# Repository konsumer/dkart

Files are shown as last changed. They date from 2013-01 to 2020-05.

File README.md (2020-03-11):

# dkart

An open-hardware and software Gameboy flash-cart and hardware peripheral framework that uses off-the-shelf hardware. The goal is to be ultra-cheap and simple.

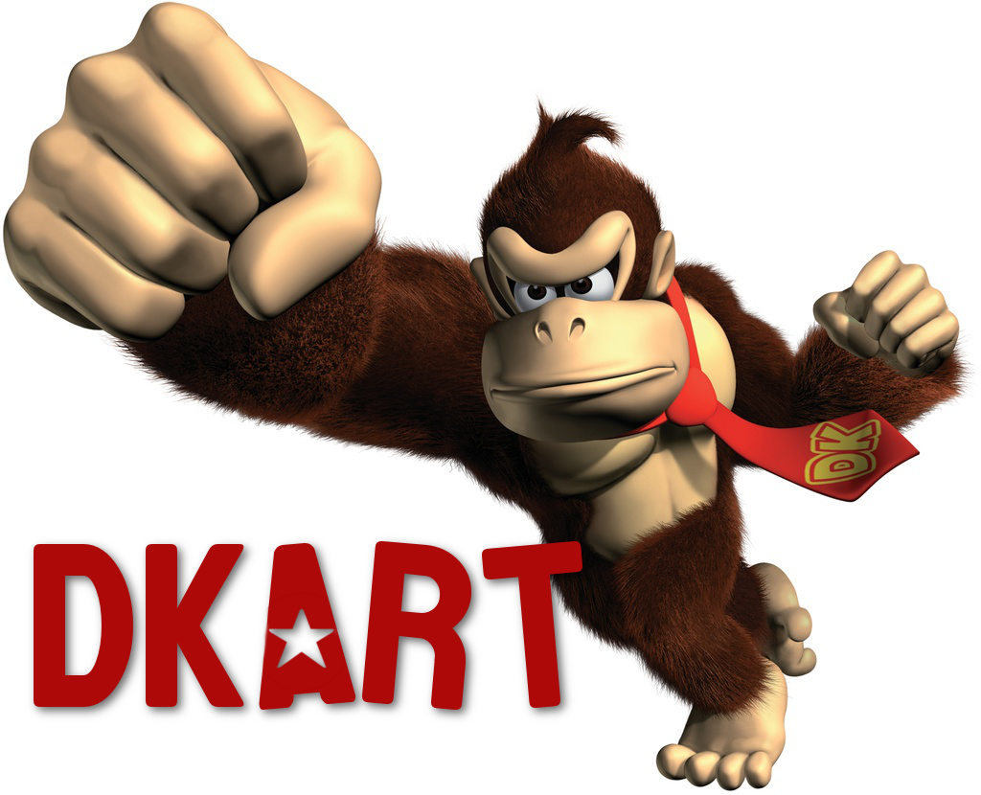
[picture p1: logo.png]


## quickstart

If you just want to get started, go to [releases](https://github.com/konsumer/dkart/releases) and grab `dkart.gb`, and put it on a FAT32-formatted SDCard. Solder together the hardware, plug it in, and startup your gameboy.

## Hardware

It's meant to be very cheap & easy to put together. I made a PCB, and you can just solder in a [cheap ESP32 board](https://www.banggood.com/Geekcreit-ESP32-WiFibluetooth-Development-Board-Ultra-Low-Power-Consumption-Dual-Cores-Unsoldered-p-1214159.html) and the [SDCard shield](https://www.banggood.com/SD-Card-Module-Slot-Socket-Reader-Mp3-player-p-74105.html), and it should work.

Originally, I designed this as a custom circuit with really low-resource chips, but realized it was much easier and cheaper to just use more modern ready-made stuff.

Eventually I'd like to add an i2c bus that can be triggered/read from gameboy, so users can easily mess with hardware peripherals.

I am still working on the PCB & schematic. You can open hardware/Dkart.json at [easyeda](https://easyeda.com/).

### under consideration

Here are some other ideas I am looking at:

* [STM32F401](https://www.banggood.com/STM32F401-Development-Board-STM32F401CCU6-STM32F4-Learning-Board-p-1568897.html)
* [This board](https://www.banggood.com/LILYGO-TTGO-T2-ESP32-0_95-OLED-SD-Card-WiFi-bluetooth-Module-Development-Board-p-1270477.html) has a SDCard and OLED screen (and wifi/bluetooth)
* [cheap atmega2560 board](https://robotdyn.com/mega-2560-pro-mini-atmega2560-16au.html), works with arduino & has more IO/RAM/CPU, but still not big enough to hold every ROM
* [fast flash mem](https://www.sparkfun.com/products/15809) - I could load the rom & ram into flash temporarily on a lower-end microcontroller, then feed the data to the GB.
* [something like this](https://www.banggood.com/GY-Openlog-Cleanflight-Naze32-F3-Blackbox-Flash-Recorder-Module-p-1309673.html) has a lot of storage (32GB) but might not be fast enough
* [ready-made cart PCB](https://store.kitsch-bent.com/product/kk_gb_brkout) - with a little simple soldering and a big flash chip, I could probly get it all to fit inside a cartridge
* [something like this](http://ww1.microchip.com/downloads/en/DeviceDoc/20005023B.pdf) could be hooked up directly to GB pins, with maybe a little simple mode-management from a micro
* [sdfat](https://github.com/greiman/SdFat-beta) can do 3965.11 KB/Sec transfer in dedicated SPI with a slow cad, which should be fast enough
* [better SDCards](https://www.cameramemoryspeed.com/sd-memory-card-faq/fastest-memory-card/) can go much faster, so make sure to check SD speed (SDFst has a `bench` sketch)
* 3d print longer cart to hold more electronics if needed. [here](https://www.thingiverse.com/thing:2882206) are some nice variations. [Here](https://www.thingiverse.com/thing:3101147) is a nice modular design (opnscad - chnage logo, etc)
* I have a [ATxmega128A1 breakout](https://www.sparkfun.com/products/retired/9546) laying around, but it's discontinued at sparkfun. It has 78 IO and 32 MIPS! It only has 128kB of flash memory & 8 kB SRAM, but could be used easily with other things, possibly SD alone is fast enough.
* look at [this ESP32 cart](https://hackaday.io/project/20769-wifi-game-boy-cartridge). They have a lot of the same ideas.

## Firmware

The firmware runs on the device to emulate ROM/RAM reading/writing data to a microSD card formatted FAT16/FAT32/ExFat. The firmware is meant to be compiled in Arduino IDE. If you open serial-monitor when it's running, you'll see some debugging output. On Arch Linux, I had to use `arduino-PR-beta1.9-BUILD-117` for serial-monitor to work, due to some java error.

Files should all be in the root of the SDCard. The fRAM-size is 128K so you may hit limits if you have a ton of ROM files on the SD (limit should be around 8,737.) The file-list uses ROM-header-title, so if you have a bunch of the same ROM file-named differently, it will work, but in the ROM-list they will all have the same name. You can use this trick to have different copies of the same ROM with separate RAM files (like 1-per-song for nanoloop, for example.)

## Software

A menu runs on the Gameboy to choose the current ROM/RAM. When a ROM is chosen, the gameboy reboots using that ROM/RAM.

To compile, run

```sh
make
```

in the software directory. 

You can read more about it in [software](./software/README.md).

## TODO

* Actually Implement MBC1
* Get SD-loading working (on boot load into RAM from SD while playing logo)
* Get menu working (get list of ROMs from firmware, on menu selection, set mem, load on reboot & clear mem)
* Implement MBC5
* Replace Nintendo logo with mine
* add extra IO-functionality, reading/writing to a specific memory location to turn on "I/O mode" and be able to interface with other peripherals
* Add support for sub-directories
* Create a modern cross-platform GBDK-focused full dev-env (use wine & docker to run stuff like GBTD.) Alternately, write some web-based tools around GBDK.js to allow sprite/map/sound editing.

## License

* Hardware is licensed 
* Firmware & Software is licensed GPLv3

## Thanks

* Lots of hardware/firmware ideas from [here](https://dhole.github.io/post/gameboy_cartridge_emu_1/)
* Ideas for menu ROM programming from [gbdk_playground](https://github.com/mrombout/gbdk_playground), [gbdk-salvage](https://github.com/gbdk-salvage/grooves-game-boy-programming), & [GBSoundDemo](https://github.com/Zal0/GBSoundDemo)

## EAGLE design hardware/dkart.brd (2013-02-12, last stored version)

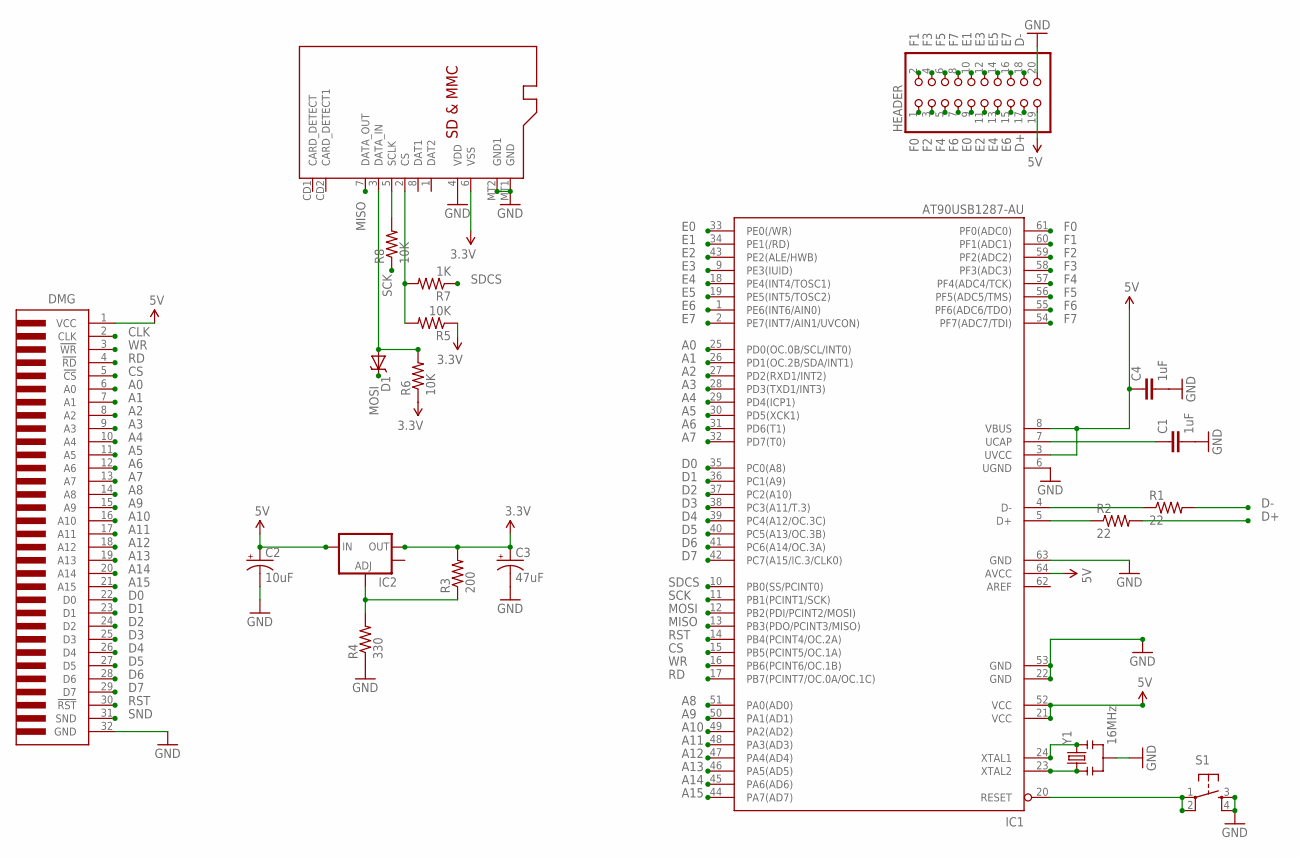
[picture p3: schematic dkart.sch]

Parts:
C1, C4: 1uF; 0805
C2: 10uF; EIA3528-KIT
C3: 47uF; EIA3528-KIT
D1: B340A; SMA-DIODE
DMG: GBCART-FULL; GBCART
HEADER: PINHD-2X10/90; 2X10/90
IC1: AT90USB1287-AU; TQFP64
IC2: V_REG_LM1117SOT223; SOT223
R1, R2: 22; 0805
R3: 200; 0805
R4: 330; 0805
R5, R6, R8: 10K; 0805
R7: 1K; 0805
S1: TAC_SWITCHSMD; TACTILE_SWITCH_SMD
SD: MICROSD
Y1: 16MHz; RESONATOR-SMD

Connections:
3.3V: C3.A (+), IC2.2 (OUT), R3.2, R5.1, R6.1, SD.6 (VSS)
5V: C2.A (+), C4.1, DMG.1 (VCC), HEADER.19, IC1.3 (UVCC), IC1.8 (VBUS), IC1.21 (VCC), IC1.52 (VCC), IC1.64 (AVCC), IC2.3 (IN)
A0: DMG.6 (A0), IC1.25 (PD0(OC.0B/SCL/INT0))
A1: DMG.7 (A1), IC1.26 (PD1(OC.2B/SDA/INT1))
A2: DMG.8 (A2), IC1.27 (PD2(RXD1/INT2))
A3: DMG.9 (A3), IC1.28 (PD3(TXD1/INT3))
A4: DMG.10 (A4), IC1.29 (PD4(ICP1))
A5: DMG.11 (A5), IC1.30 (PD5(XCK1))
A6: DMG.12 (A6), IC1.31 (PD6(T1))
A7: DMG.13 (A7), IC1.32 (PD7(T0))
A8: DMG.14 (A8), IC1.51 (PA0(AD0))
A9: DMG.15 (A9), IC1.50 (PA1(AD1))
A10: DMG.16 (A10), IC1.49 (PA2(AD2))
A11: DMG.17 (A11), IC1.48 (PA3(AD3))
A12: DMG.18 (A12), IC1.47 (PA4(AD4))
A13: DMG.19 (A13), IC1.46 (PA5(AD5))
A14: DMG.20 (A14), IC1.45 (PA6(AD6))
A15: DMG.21 (A15), IC1.44 (PA7(AD7))
CLK: DMG.2 (CLK)
CS: DMG.5 (!CS), IC1.15 (PB5(PCINT5/OC.1A))
D0: DMG.22 (D0), IC1.35 (PC0(A8))
D1: DMG.23 (D1), IC1.36 (PC1(A9))
D2: DMG.24 (D2), IC1.37 (PC2(A10))
D3: DMG.25 (D3), IC1.38 (PC3(A11/T.3))
D4: DMG.26 (D4), IC1.39 (PC4(A12/OC.3C))
D5: DMG.27 (D5), IC1.40 (PC5(A13/OC.3B))
D6: DMG.28 (D6), IC1.41 (PC6(A14/OC.3A))
D7: DMG.29 (D7), IC1.42 (PC7(A15/IC.3/CLK0))
D+: HEADER.17, R2.2
D-: HEADER.18, R1.2
E0: HEADER.9, IC1.33 (PE0(/WR))
E1: HEADER.10, IC1.34 (PE1(/RD))
E2: HEADER.11, IC1.43 (PE2(ALE/HWB))
E3: HEADER.12, IC1.9 (PE3(IUID))
E4: HEADER.13, IC1.18 (PE4(INT4/TOSC1))
E5: HEADER.14, IC1.19 (PE5(INT5/TOSC2))
E6: HEADER.15, IC1.1 (PE6(INT6/AIN0))
E7: HEADER.16, IC1.2 (PE7(INT7/AIN1/UVCON))
F0: HEADER.1, IC1.61 (PF0(ADC0))
F1: HEADER.2, IC1.60 (PF1(ADC1))
F2: HEADER.3, IC1.59 (PF2(ADC2))
F3: HEADER.4, IC1.58 (PF3(ADC3))
F4: HEADER.5, IC1.57 (PF4(ADC4/TCK))
F5: HEADER.6, IC1.56 (PF5(ADC5/TMS))
F6: HEADER.7, IC1.55 (PF6(ADC6/TDO))
F7: HEADER.8, IC1.54 (PF7(ADC7/TDI))
GND: C1.2, C2.C (-), C3.C (-), C4.2, DMG.32 (GND), HEADER.20, IC1.6 (UGND), IC1.22 (GND), IC1.53 (GND), IC1.63 (GND), R4.1, S1.3, S1.4, SD.4 (VDD), SD.MT1 (GND), SD.MT2 (GND1), Y1.2
MISO: IC1.13 (PB3(PDO/PCINT3/MISO)), SD.7 (DATA_OUT)
MOSI: D1.C, IC1.12 (PB2(PDI/PCINT2/MOSI))
unnamed: IC1.24 (XTAL1), Y1.3
unnamed: IC1.23 (XTAL2), Y1.1
unnamed: IC1.20 (RESET), S1.1, S1.2
unnamed: IC1.5 (D+), R2.1
unnamed: IC1.4 (D-), R1.1
unnamed: C1.1, IC1.7 (UCAP)
unnamed: IC2.1 (ADJ), R3.1, R4.2
unnamed: R8.2, SD.5 (SCLK)
unnamed: D1.A, R6.2, SD.3 (DATA_IN)
unnamed: R5.2, R7.2, SD.2 (CS)
RD: DMG.4 (!RD), IC1.17 (PB7(PCINT7/OC.0A/OC.1C))
RST: DMG.30 (!RST), IC1.14 (PB4(PCINT4/OC.2A))
SCK: IC1.11 (PB1(PCINT1/SCK)), R8.1
SDCS: IC1.10 (PB0(SS/PCINT0)), R7.1
SND: DMG.31 (SND)
WR: DMG.3 (!WR), IC1.16 (PB6(PCINT6/OC.1B))

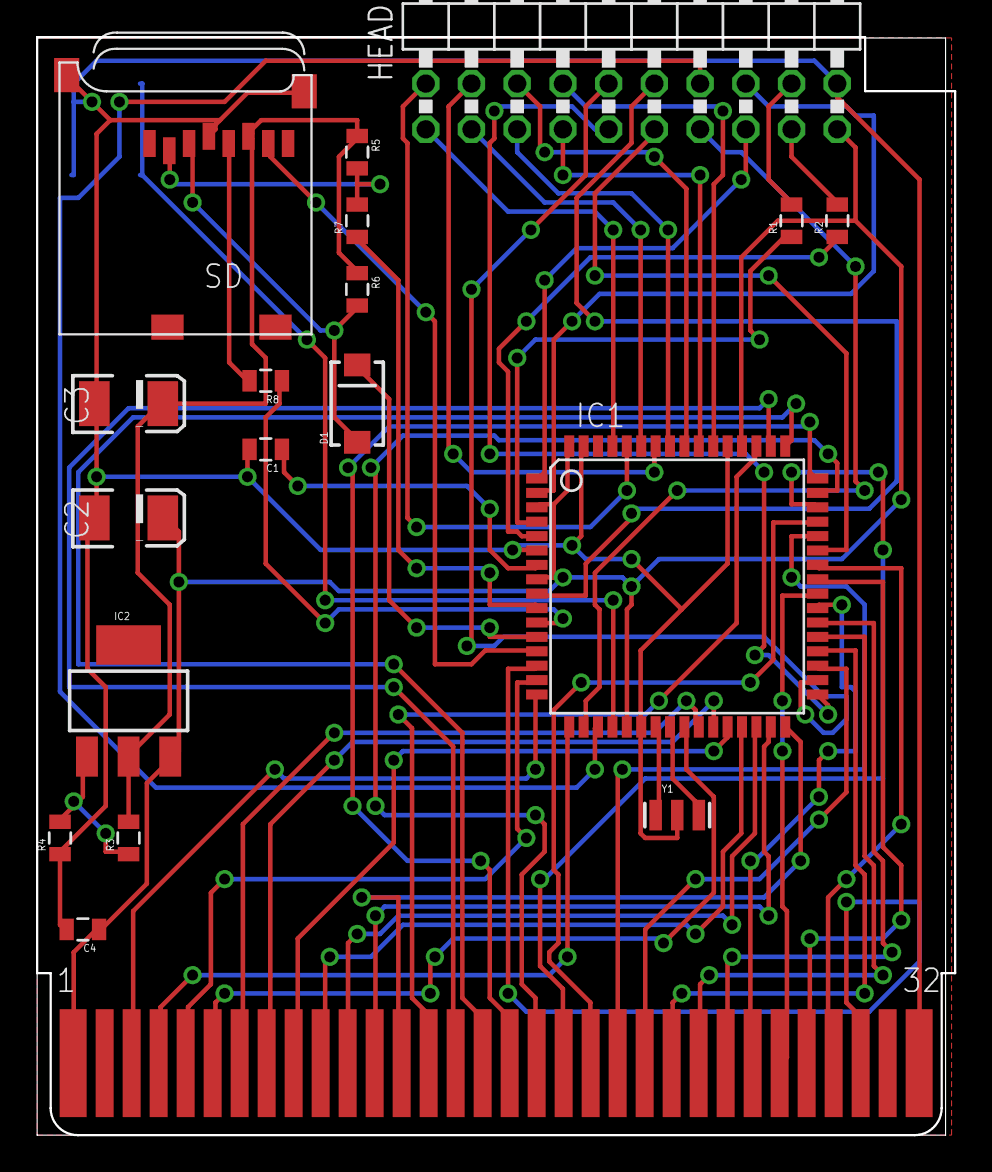
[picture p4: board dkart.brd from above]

Board: 2 copper layers, 51.0 x 61.0 mm, 20 parts (1 on the bottom side), 63 nets.

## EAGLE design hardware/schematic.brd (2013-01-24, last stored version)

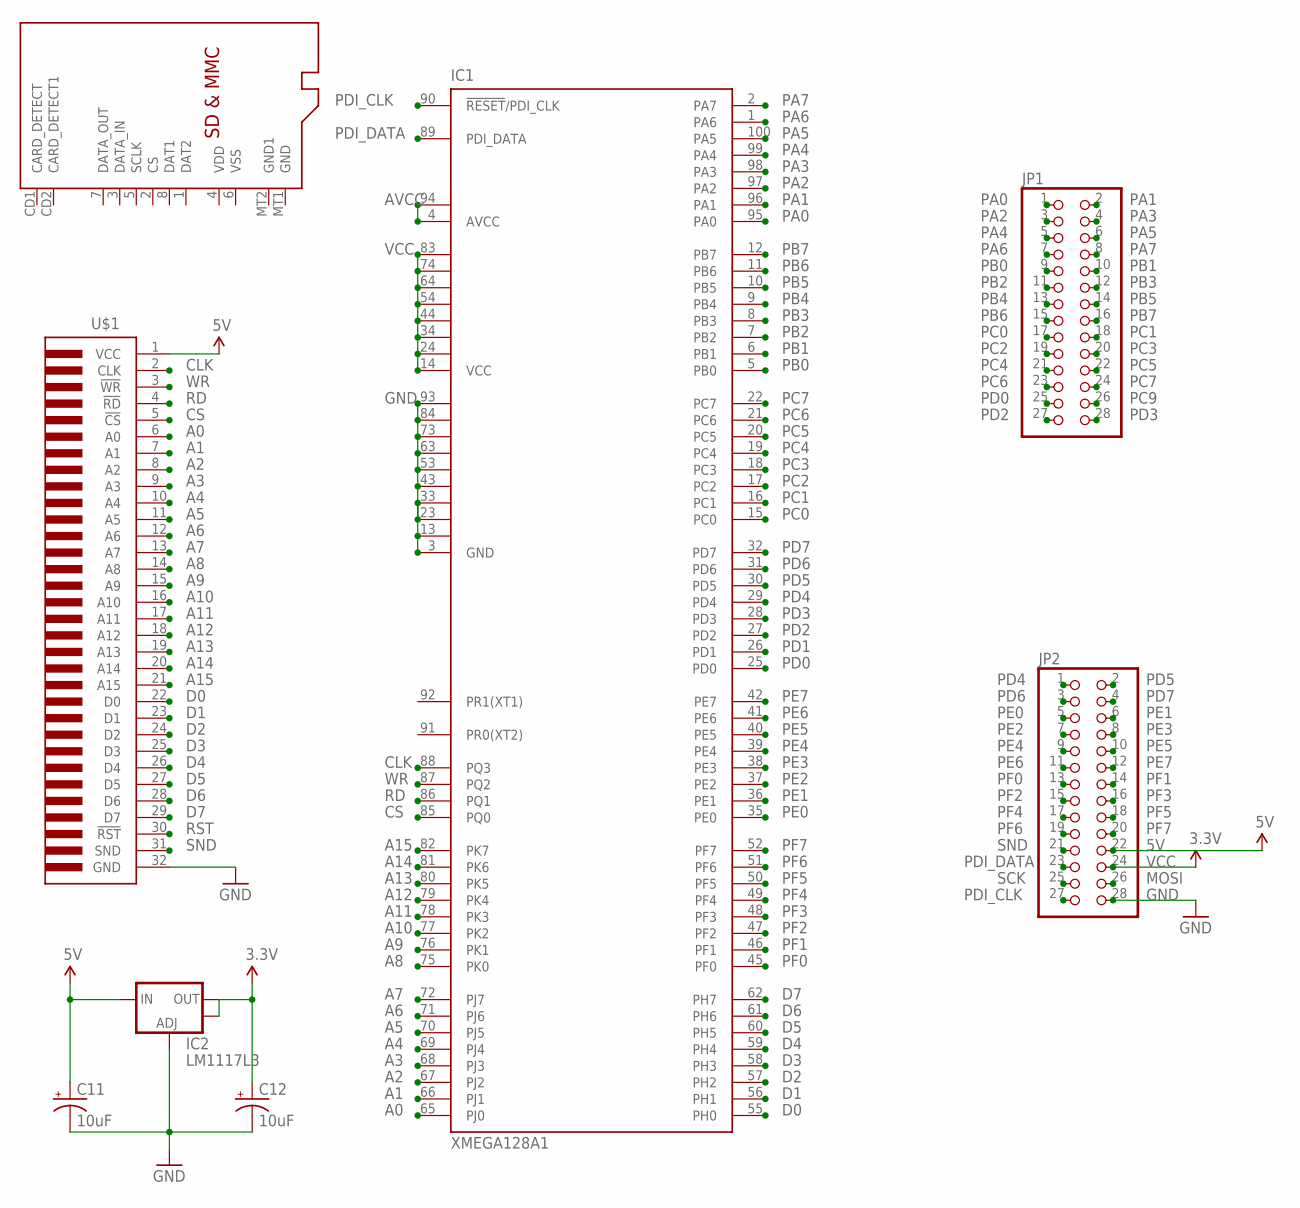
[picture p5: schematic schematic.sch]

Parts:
C11, C12: 10uF; EIA3216
IC1: XMEGA128A1; TQFP100
IC2: LM1117L3; SOT223
JP1, JP2: PINHD-2X14-CB; 2X14-CLEANBIG
U$1: GBCART-FULL; GBCART
U$5: MICROSD

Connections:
5V: C11.A (+), IC2.3 (IN), JP2.22, U$1.1 (VCC)
A0: IC1.65 (PJ0), U$1.6 (A0)
A1: IC1.66 (PJ1), U$1.7 (A1)
A2: IC1.67 (PJ2), U$1.8 (A2)
A3: IC1.68 (PJ3), U$1.9 (A3)
A4: IC1.69 (PJ4), U$1.10 (A4)
A5: IC1.70 (PJ5), U$1.11 (A5)
A6: IC1.71 (PJ6), U$1.12 (A6)
A7: IC1.72 (PJ7), U$1.13 (A7)
A8: IC1.75 (PK0), U$1.14 (A8)
A9: IC1.76 (PK1), U$1.15 (A9)
A10: IC1.77 (PK2), U$1.16 (A10)
A11: IC1.78 (PK3), U$1.17 (A11)
A12: IC1.79 (PK4), U$1.18 (A12)
A13: IC1.80 (PK5), U$1.19 (A13)
A14: IC1.81 (PK6), U$1.20 (A14)
A15: IC1.82 (PK7), U$1.21 (A15)
AVCC: IC1.4 (AVCC), IC1.94 (AVCC1)
CLK: IC1.88 (PQ3), U$1.2 (CLK)
CS: IC1.85 (PQ0), U$1.5 (!CS)
D0: IC1.55 (PH0), U$1.22 (D0)
D1: IC1.56 (PH1), U$1.23 (D1)
D2: IC1.57 (PH2), U$1.24 (D2)
D3: IC1.58 (PH3), U$1.25 (D3)
D4: IC1.59 (PH4), U$1.26 (D4)
D5: IC1.60 (PH5), U$1.27 (D5)
D6: IC1.61 (PH6), U$1.28 (D6)
D7: IC1.62 (PH7), U$1.29 (D7)
GND: C11.C (-), C12.C (-), IC1.3 (GND), IC1.13 (GND1), IC1.23 (GND2), IC1.33 (GND3), IC1.43 (GND4), IC1.53 (GND5), IC1.63 (GND6), IC1.73 (GND7), IC1.84 (GND8), IC1.93 (GND9), IC2.1 (ADJ), JP2.28, U$1.32 (GND)
MOSI: JP2.26
PA0: IC1.95 (PA0), JP1.1
PA1: IC1.96 (PA1), JP1.2
PA2: IC1.97 (PA2), JP1.3
PA3: IC1.98 (PA3), JP1.4
PA4: IC1.99 (PA4), JP1.5
PA5: IC1.100 (PA5), JP1.6
PA6: IC1.1 (PA6), JP1.7
PA7: IC1.2 (PA7), JP1.8
PB0: IC1.5 (PB0), JP1.9
PB1: IC1.6 (PB1), JP1.10
PB2: IC1.7 (PB2), JP1.11
PB3: IC1.8 (PB3), JP1.12
PB4: IC1.9 (PB4), JP1.13
PB5: IC1.10 (PB5), JP1.14
PB6: IC1.11 (PB6), JP1.15
PB7: IC1.12 (PB7), JP1.16
PC0: IC1.15 (PC0), JP1.17
PC1: IC1.16 (PC1), JP1.18
PC2: IC1.17 (PC2), JP1.19
PC3: IC1.18 (PC3), JP1.20
PC4: IC1.19 (PC4), JP1.21
PC5: IC1.20 (PC5), JP1.22
PC6: IC1.21 (PC6), JP1.23
PC7: IC1.22 (PC7), JP1.24
PC9: JP1.26
PD0: IC1.25 (PD0), JP1.25
PD1: IC1.26 (PD1)
PD2: IC1.27 (PD2), JP1.27
PD3: IC1.28 (PD3), JP1.28
PD4: IC1.29 (PD4), JP2.1
PD5: IC1.30 (PD5), JP2.2
PD6: IC1.31 (PD6), JP2.3
PD7: IC1.32 (PD7), JP2.4
PDI_CLK: IC1.90 (!RESET!/PDI_CLK), JP2.27
PDI_DATA: IC1.89 (PDI_DATA), JP2.23
PE0: IC1.35 (PE0), JP2.5
PE1: IC1.36 (PE1), JP2.6
PE2: IC1.37 (PE2), JP2.7
PE3: IC1.38 (PE3), JP2.8
PE4: IC1.39 (PE4), JP2.9
PE5: IC1.40 (PE5), JP2.10
PE6: IC1.41 (PE6), JP2.11
PE7: IC1.42 (PE7), JP2.12
PF0: IC1.45 (PF0), JP2.13
PF1: IC1.46 (PF1), JP2.14
PF2: IC1.47 (PF2), JP2.15
PF3: IC1.48 (PF3), JP2.16
PF4: IC1.49 (PF4), JP2.17
PF5: IC1.50 (PF5), JP2.18
PF6: IC1.51 (PF6), JP2.19
PF7: IC1.52 (PF7), JP2.20
RD: IC1.86 (PQ1), U$1.4 (!RD)
RST: U$1.30 (!RST)
SCK: JP2.25
SND: JP2.21, U$1.31 (SND)
VCC: C12.A (+), IC1.14 (VCC), IC1.24 (VCC1), IC1.34 (VCC2), IC1.44 (VCC3), IC1.54 (VCC4), IC1.64 (VCC5), IC1.74 (VCC6), IC1.83 (VCC7), IC2.2 (OUT), IC2.4 (OUT), JP2.24
WR: IC1.87 (PQ2), U$1.3 (!WR)

Board: 2 copper layers, 8 parts (0 on the bottom side), 82 nets, no tracks yet.

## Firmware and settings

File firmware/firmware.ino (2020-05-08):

/*
HARDWARE:

ESP32: https://www.banggood.com/Geekcreit-ESP32-WiFibluetooth-Development-Board-Ultra-Low-Power-Consumption-Dual-Cores-Unsoldered-p-1214159.html
SDCard hooked to P5 (SS), P18 (SCK), P19 (MISO), P23 (MOSI)

Currently this just builds a dkart.sav from the current file-list
*/

// use https://github.com/greiman/SdFat-beta
#include "SdFat.h"

// this defines the hardware

// SD on HSPI - http://www.ayarafun.com/wp-content/uploads/2016/11/esp32-pinout.png
// MISO - 12
// MOSI - 13
// SCK - 14
// SS - 15

// https://dhole.github.io/media/gameboy_stm32f4/gb_cartridge_pins.jpg

// it's maxed-out, so no i2c or serial or wifi
// probly should use a shift-in (like 74F676) to handle GB address
// with i2s sort of like this:
// https://github.com/Crypter/CryptoIO
// https://github.com/lhartmann/esp8266_reprap
// https://esp32.com/viewtopic.php?f=17&t=3188
// i2s allows very fast low-cpu serial

#define GB_A0  GPIO36
#define GB_A1  GPIO39
#define GB_A2  GPIO34
#define GB_A3  GPIO35
#define GB_A4  GPIO32
#define GB_A5  GPIO33
#define GB_A6  GPIO25
#define GB_A7  GPIO26
#define GB_A8  GPIO27
#define GB_A9  GPIO09
#define GB_A10 GPIO10
#define GB_A11 GPIO11
#define GB_A12 GPIO23
#define GB_A13 GPIO22
#define GB_A14 GPIO01
#define GB_A15 GPIO03

#define GB_D0  GPIO21
#define GB_D1  GPIO19
#define GB_D2  GPIO18
#define GB_D3  GPIO05
#define GB_D4  GPIO17
#define GB_D5  GPIO16
#define GB_D6  GPIO04
#define GB_D7  GPIO00

#define GB_WR  GPIO02
#define GB_RD  GPIO08
#define GB_CLK GPIO07
#define GB_CS  GPIO06

// #define GB_RST
#define GB_AUD ADC12 // GPIO02

// this is maybe a bit specifc to my hardware, see SdFat examples to tune to yours, if needed
#define SD_CONFIG SdSpiConfig(SS, DEDICATED_SPI, SD_SCK_MHZ(16))

#define error(s) { errState = true; sd.errorHalt(&Serial, F(s)); }
#define interval 500

// This figures out correct filesystem (EX/FAT16/32)
SdFs sd;
FsFile file;
FsFile root;
FsFile sav;

char romName[15];

unsigned long romCount = 0;
char currentRom[255] = "dkart.gb";
char currentSav[255] = "dkart.sav";

bool errState = false;

// async LED blinker to show error-state
int ledState = LOW;
unsigned long previousMillis = 0;
unsigned long currentMillis = 0;
void ledBlink () {
  currentMillis = millis();
  if (currentMillis - previousMillis >= interval) {
    previousMillis = currentMillis;
    ledState = ledState == LOW ? HIGH : LOW;
    digitalWrite(LED_BUILTIN, ledState);
  }
}

void setup() {
  pinMode(LED_BUILTIN, OUTPUT);

  Serial.begin(115200);

  if (!sd.begin(SD_CONFIG)) {
    errState = true;
    sd.initErrorHalt(&Serial);
  }

  // TODO: use GB-CLK interrupt to sleep/read
  // TODO: lookup currentRom from EEPROM/SDCard
  // TODO: derive currentSav filename from currentRom

  // read file-list into dkart.sav
  if (!root.open("/")) {
    error("open root");
  }
  
  if (!sav.open(currentSav, O_CREAT|O_WRITE)) {
    error("creating SAV");
  }
  
  romCount = 0;
  sav.seek(4);
  while (file.openNext(&root, O_RDONLY)) {
     char fname[255];
     file.getName(fname, 255);
     Serial.println(fname);
     if (!file.isHidden() && !file.isSubDir() && strcmp(".gb", &fname[ strlen(fname) - 3 ]) == 0 && strcmp("dkart.gb", fname) != 0) {
      file.seek(0x0134);
      file.read(romName, 15);
      sav.write(fname, 15);
      romCount++;
     }
     file.close();
  }
  
  // turn romCount into 4-bytes at beginning of file
  byte rc[4] = {
    romCount & 0xFF,
    (romCount >> 8) & 0xFF,
    (romCount >> 16) & 0xFF,
    (romCount >> 24) & 0xFF    
  };
  sav.seek(0);
  sav.write(rc, 4);
  
  // 0-fill to 32768 (the RAM size in dkart ROM-header)
  unsigned long zeroCount = 32768 - (romCount * 0x0F) - 4;
  sav.seek((romCount * 0x0F) + 4);
  while(zeroCount){
    sav.write("\0", 1);
    zeroCount--;
  }

  sav.close();
  
  Serial.write("ROMS Found: ");
  Serial.println(romCount);
}

void loop() {
  if (errState) {
    ledBlink();
  }
}

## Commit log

2013-01-23 improved menu to demo basic flow
2013-01-24 starting over with new hardware ideas
    [schematic.brd, schematic.sch]
2013-01-24 added experiment cart
    [schematic.brd, schematic.sch]
2013-02-12 working on using at90usb1287
    [dkart.brd, dkart.sch, experiment_cart.brd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]
2013-02-12 moved USB to header
    [dkart.brd, dkart.sch]
2013-02-12 board design complete, improved schematic, ready for hardware testing
    [dkart.brd, dkart.sch]
2013-05-20 improved hardware design
    [experiment_cart.brd]
2020-03-04 move to STM32F401
    [dkart.brd, dkart.sch, experiment_cart.brd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]
2020-03-04 no arduino
2020-03-06 notes about 3d printing
2020-03-08 use local vars to track menu, for better perf
2020-03-09 start of PCB
2020-03-10 starting work on new SRAM idea - broken for now
    [firmware.ino]
2020-03-10 I think firmware bytes for count were reversed
    [firmware.ino]
2020-03-11 async LED blinker for errors in firmware
    [firmware.ino]

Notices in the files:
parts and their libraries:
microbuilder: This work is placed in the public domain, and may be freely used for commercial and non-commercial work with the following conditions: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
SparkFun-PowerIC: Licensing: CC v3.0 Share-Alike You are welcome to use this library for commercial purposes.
